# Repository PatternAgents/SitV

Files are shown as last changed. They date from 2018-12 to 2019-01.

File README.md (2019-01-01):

# Spoken into the Void - 




"Spoken into the Void" is an CPU upgrade/add-on for the Teensy3.2 CPU to the larger Teensy 3.5/3.6 CPU, 
yielding more memory space and other resouces. The upgrade is simple, remove the existing Teensy3.2 CPU, 
and plug in the "Spoken into the Void" board in it's place.

"Spoken into the Void" has the following features :

* Breadboard Friendly and Eurorack 3U/8HP compatible
* Teensy 3.6 Based (32 bit 120/240 MHz ARM Cortex-M4 processor with floating point unit and DSP)
* 4X Flash Upgrade (1.0 Megabyte)
* 4X RAM Upgrade   (256 Kilobytes)
* Supports up to two(2) Teensy Audio Shields for four(4) channel 16-bit Audio I/O
* 4X (optional/external)  Analog to digital converters (ADS1115 16-bit) for independent CV sampling
* USB Full-Speed Device (USB Audio, MIDI, COM, HID)
* USB Full-Speed Host (USB Keyboard, peripherals)
* Two  (2) AC coupled, line level audio input channels 
* Two  (2) AC coupled, line level audio output channels
* UART Jack for Serial MIDI Expansion
* I2C Jack for Controls & UI Expansion
* 32K bytes NVSRAM (non-volatile memory) for configuration memory (with Embedis support)

Format : Eurorack (3U/8HP)

Dimensions :  110mm x 40mm

Power : +5V (USB) 200mA

Jacks(Grove) : Stereo Line Input, Stereo Line Output, UART, I2C

---------------------------------------

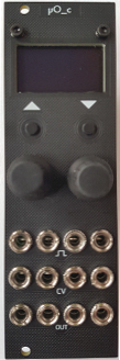
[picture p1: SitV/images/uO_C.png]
micro:O&C (https://github.com/patternagents/SitV)
  SitV (https://www.youtube.com/watch?v=XBFi51OQsEs)

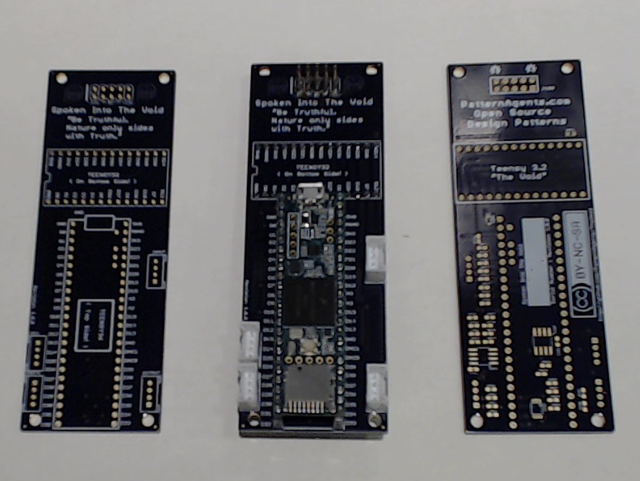
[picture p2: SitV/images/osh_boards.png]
SitV
[SitV](https://github.com/PatternAgents/SitV)

---------------------------------------
## SitV Applications <a name="SitV_Applications"/>

"Spoken into the Void" upgrades a [Teensy3.2 embedded CPU](https://www.pjrc.com/store/teensy32.html) Socket to accept the larger [Teensy 3.6 embedded CPU](https://www.pjrc.com/store/teensy36.html) module.
"Spoken into the Void" is designed to be compatible with the [Teensy Audio Shield](https://www.pjrc.com/store/teensy3_audio.html),
and can accept up to two shields, supporting up to four (4) 16 bit audio channels.

- "SitV" is also "breadboard friendly" and can be used to develop other circuits based on the Teensy 3.6 embedded CPU module
together with several Teensy Audio Modules.
- "SitV" can also be used with the [8HP micro:Ornament and Crime Eurorack module from JakPlug](https://github.com/jakplugg/uO_c)
- "SitV" can also be used with the [8HP micro:Temps Utile Eurorack module from JakPlug](https://github.com/jakplugg/T_u)

"SitV" is primarily a firmware development and testing tool, 
for developing new Eurorack based synthesizer modules and firmware.

----------------------------------------
## DSP Audio Pipeline

(Performance Test Pipeline - Subject to change in final versions!)
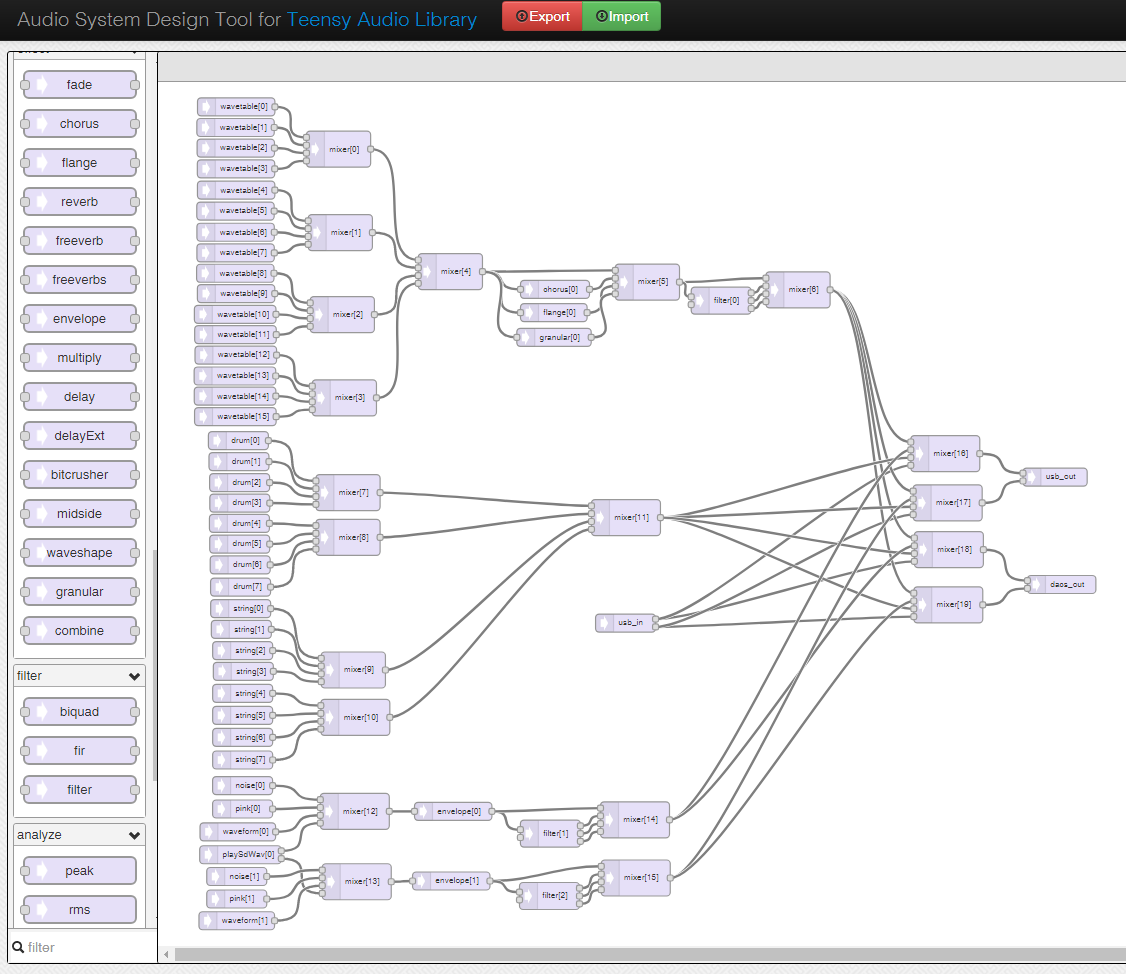
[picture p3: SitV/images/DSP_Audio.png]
SitV DSP Pipeline
[Spoken into the Void - DSP Pipeline](https://github.com/patternagents/SitV)

- 16 Wavetable Voices (with FX)
- 8 Drum Voices
- 8 String Voices
- 2 Noise/Complex Voices
- 2 SDcard .wav file Voices
- 2 USB Inputs
- 2 USB Outputs
- 2 Audio DAC (Line) Outputs

---------------------------------------
## SitV Status <a name="SitV_Status"/>

**11/28/2018:** 
- R1.0.0 : Initial Layout sent to OSHpark

**12/14/2018:**
- R1.0.0 : Initial Bringup and Testing
- Teensy3.5 working correctly
- Ornament&Crime R1.3.3 Up and Running on Teensy3.5
- Ornament&Crime R1.3.3 alternate SPI pins issue with O&C Core on Teensy3.6 (not running)

**12/23/2018:**
- "Serial+MIDIx16+Audio" compiles/runs with Hemishere 1.7A on Teensy 3.5 only
- "MIDIx16" to Serial4 MIDI router tests : Working on both 3.5 & 3.6

**01/01/2019:**
- rsvp_sitv: firmware update (raw testing version) Working on both 3.5 & 3.6
- rsvp_sitv: Serial+MIDIx16+Audio, OLED drivers Working on both 3.5 & 3.6

---------------------------------------
## SitV Model Images

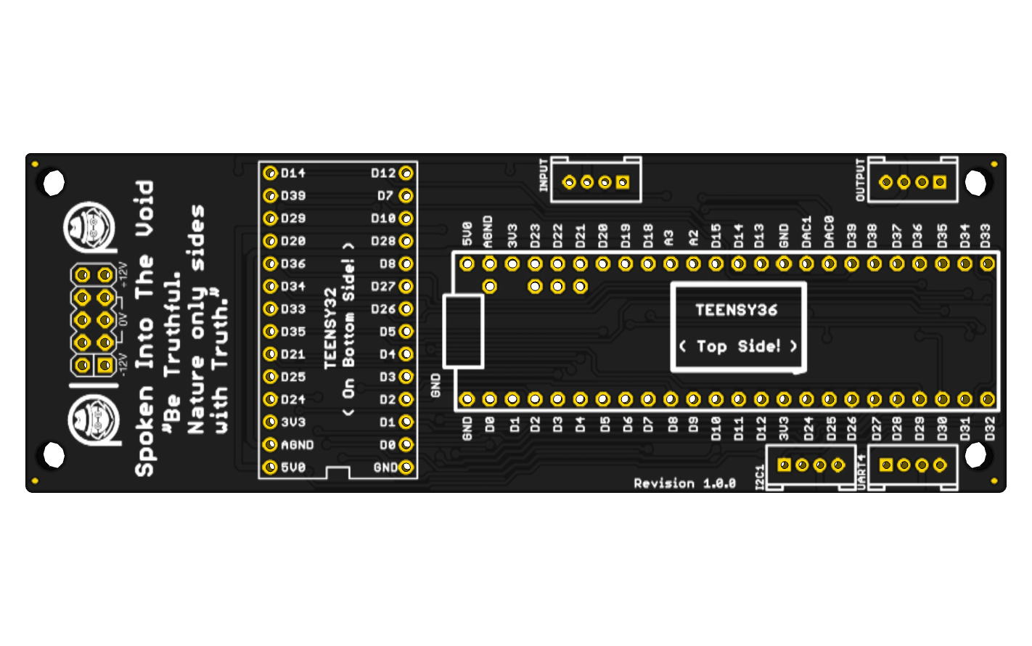
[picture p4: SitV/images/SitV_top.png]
[Spoken into the Void - Top Side](https://github.com/patternagents/SitV)

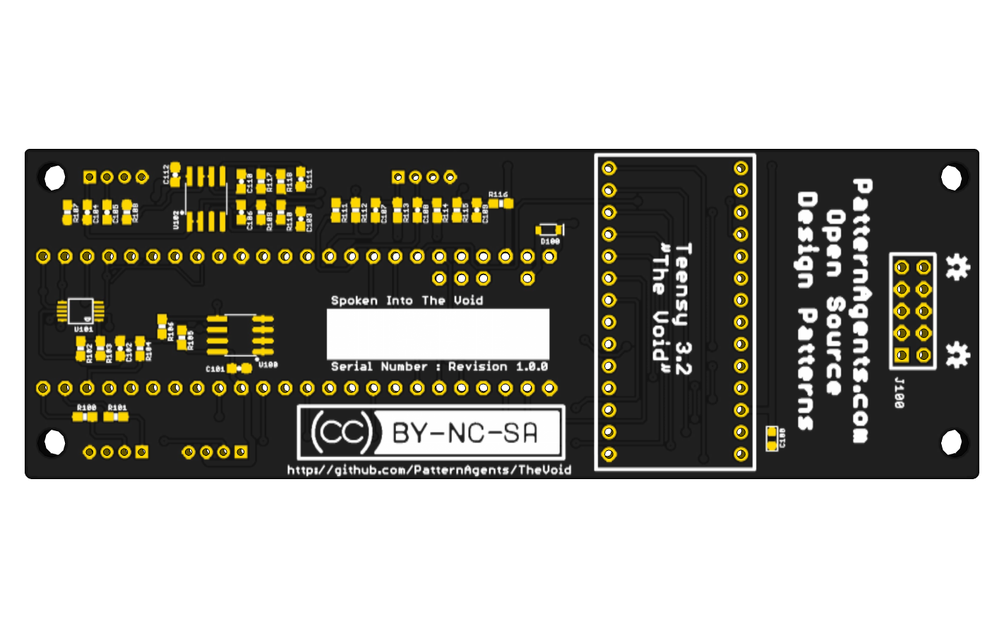
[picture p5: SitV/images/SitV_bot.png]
[Spoken into the Void - Bottom Side](https://github.com/patternagents/SitV)

---------------------------------------

## SitV Documentation Index <a name="TheVoid_documentation_index"/>

[Ornament and Crime](http://ornament-and-cri.me/)

[micro:Ornament and Crime](https://github.com/jakplugg/uO_c)

[SitV Project](https://github.com/PatternAgents/SitV/wiki)

[SitV Hardware](https://github.com/patternagents/SitV/tree/master/SitV/revisions/)

---------------------------------------

## Documentation Index <a name="documentation_index"/>

[Organization Website](http://patternagents.github.io)

[FAQ - Frequently Asked Questions](http://thingsoc.github.io/support/faq.html)

---------------------------------------

[thingSoC 
*PatternAgents, LLC*](http://thingsoc.github.io)

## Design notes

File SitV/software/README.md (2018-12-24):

# Spoken Into The Void - FIRMWARE

"Spoken Into The Void" can be used in several different applications.

When used with "Ornament and Crime" compatible hardware,
the following firmware can be used :

- o_c_V1_3_3_siv : Port of Ornment & Crime Version 1.3.3 for Teensy 3.5
- o_c_hemi_V1_7A_siv : Base Port of Hemisphere Suite Version 1.7A for Teensy 3.5
- rsvp-sitv : Base Port of Embedis/RSVP for Teensy 3.6
- tests : Assorted Hardware Testing routines for Teensy 3.5/3.6

---------------------------------------

## SitV Documentation Index <a name="SitV_documentation_index"/>

[Ornament and Crime](http://ornament-and-cri.me/)

[micro:Ornament and Crime](https://github.com/jakplugg/uO_c)

[SitV Project](https://github.com/PatternAgents/SitV/wiki)

[SitV Hardware](https://github.com/patternagents/SitV/tree/master/SitV/revisions/)

---------------------------------------

## Documentation Index <a name="documentation_index"/>

[Organization Website](http://patternagents.github.io)

[FAQ - Frequently Asked Questions](http://thingsoc.github.io/support/faq.html)

---------------------------------------

[thingSoC 
*PatternAgents, LLC*](http://thingsoc.github.io)

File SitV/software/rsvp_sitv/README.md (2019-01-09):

# Spoken Into The Void - RSVP

RSVP is a simple framework for using and testing embedded systems.

RSVP uses the Embedis console to interactively enter commands for testing.

See  "SDCARD/HELP.TXT" for help

--------------------------------------
## Contents

SDCARD    - copy contents to an SDcard for the Teensy3.6

libraries - install into Arduino/Libraries

rsvp_sitv - Arduino Source code

Requirements:

Teensy3.6 Module

Formatted SDcard

Arduino 1.8.8+

TeensyDuino 1.4.5+

Settings:

240Mhz (overclock)

Serial+MIDIx16+Audio

---------------------------------------

## SitV Documentation Index <a name="SitV_documentation_index"/>

[SitV Project](https://github.com/PatternAgents/SitV/wiki)

[SitV Hardware](https://github.com/patternagents/SitV/tree/master/SitV/revisions/)

---------------------------------------

## Documentation Index <a name="documentation_index"/>

[Organization Website](http://patternagents.github.io)

[FAQ - Frequently Asked Questions](http://thingsoc.github.io/support/faq.html)

---------------------------------------

[thingSoC 
*PatternAgents, LLC*](http://thingsoc.github.io)

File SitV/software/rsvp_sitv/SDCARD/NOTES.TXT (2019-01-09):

MIDI Routing
------------

0.0.1 : Simple 1:1 MIDI Routing, no filtering
	1) latency seems high?
        2) Might need to try reducing the Audio DSP overhead
	3) Polling loop issues/slow, recode as callbacks, etc.

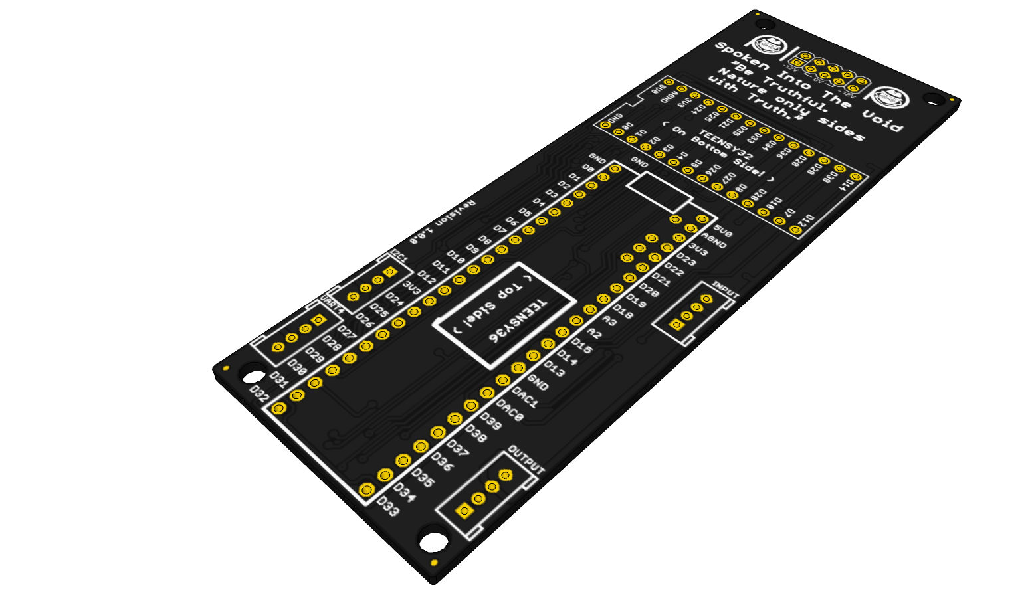
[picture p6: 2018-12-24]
SitV/images/SitV_iso.png

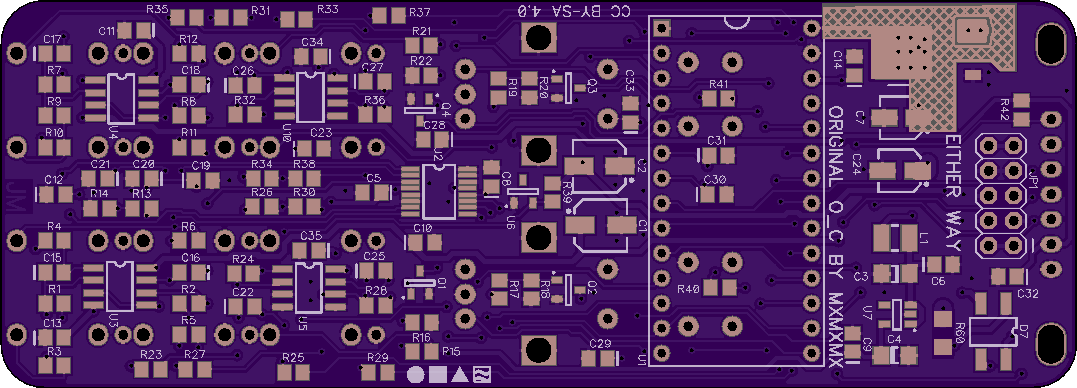
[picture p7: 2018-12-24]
SitV/images/uO_C_osh_bot.png

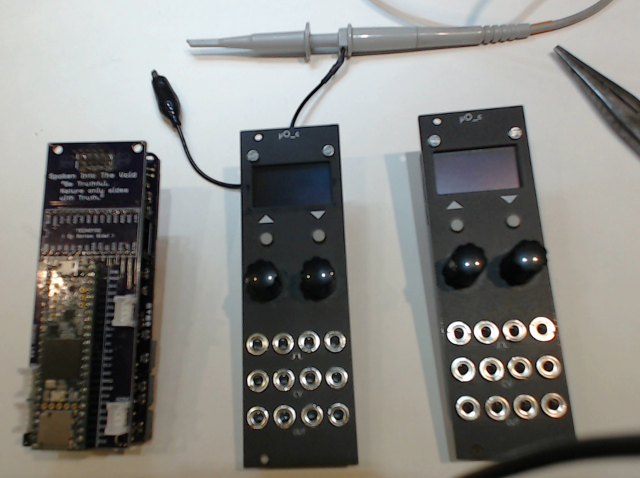
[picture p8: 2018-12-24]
SitV/images/osh_board5.png

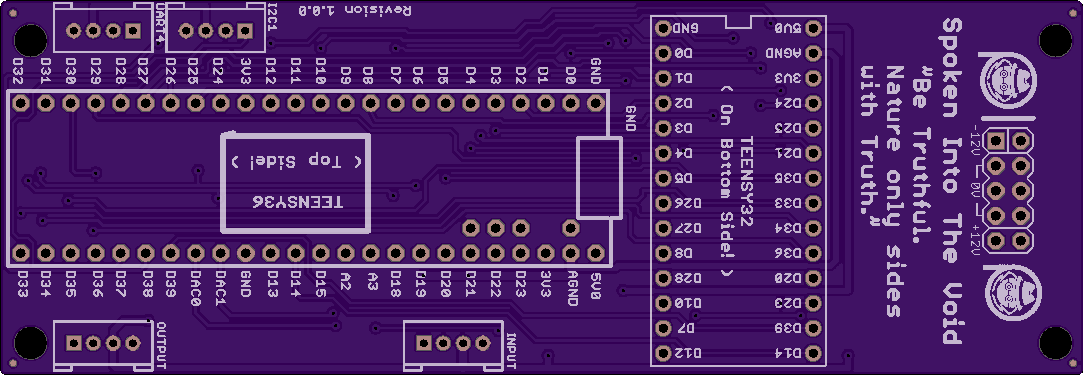
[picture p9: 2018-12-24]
SitV/images/osh_top.png

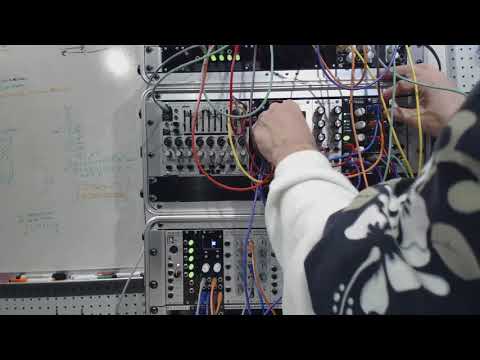
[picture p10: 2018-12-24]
SitV/images/in_rack.jpg

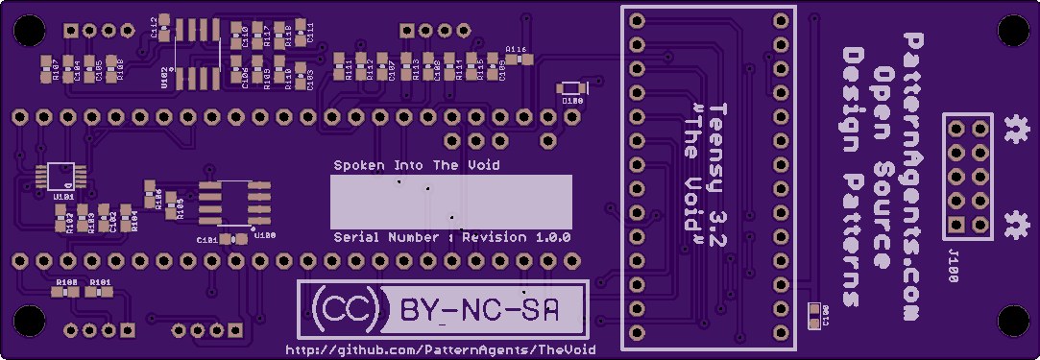
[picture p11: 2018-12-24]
SitV/images/osh_bot.png

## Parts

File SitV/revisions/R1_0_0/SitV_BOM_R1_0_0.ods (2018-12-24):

Qty | Parts | Value | Device | Price Each | Total Qty | Price Total | On Hand | Order | Source
2 | C106, C110 | 1000pF | CAP0603-CAP | 0.066 | 2 | 0.132 | 500 | 0 | https://www.mouser.com/ProductDetail/Yageo/CC0603MRX7R9BB102
4 | C100, C101, C102, C112 | 100nf | CERAMIC-100NF-50V-10%-X7R(0603) | 0.066 | 4 | 0.264 | 4000 | 0 | https://www.mouser.com/ProductDetail/Murata-Electronics/GCM033R71E471KA03D
2 | C103, C111 | 470pF | CAP0603-CAP | 0.066 | 2 | 0.132 | 500 | 0 | https://www.mouser.com/ProductDetail/Murata-Electronics/GCM033R71E471KA03D
5 | C104, C105, C107, C108, C109 | 10uF | CAP0603-CAP | 0.066 | 5 | 0.33 | 500 | 0 | https://www.mouser.com/ProductDetail/Taiyo-Yuden/JMK107BJ106MA-T
2 | R100, R101 | 1K | RESISTOR0603 | 0.02 | 2 | 0.04 | 4000 | 0 | https://www.mouser.com/ProductDetail/Yageo/RC0603FR-071KL?qs=sGAEpiMZZMtRY1MQzfviYBKl3q7m6O1t
3 | R105, R106, R115 | 2K2 | RESISTOR0603 | 0.02 | 3 | 0.06 | 4000 | 0 | https://www.mouser.com/ProductDetail/Yageo/RC0603FR-072K2L?qs=sGAEpiMZZMtRY1MQzfviYIolhRbATB6G
4 | R109, R110, R117, R118 | 7K5 | RESISTOR0603 | 0.02 | 4 | 0.08 | 0 | 100 | ttps://www.mouser.com/ProductDetail/KOA-Speer/RK73H1JTTD7501D
3 | R103, R104, R116 | 10K | RESISTOR0603 | 0.02 | 3 | 0.06 | 5000 | 0 | https://www.mouser.com/ProductDetail/Yageo/RC0603FR-0710KL?qs=sGAEpiMZZMvLNADcllXbqHQ2CGarwjoT
4 | R111, R112, R113, R114 | 47K | RESISTOR0603 | 0.02 | 4 | 0.08 | 5000 | 0 | https://www.mouser.com/ProductDetail/Yageo/RC0603FR-0747KL?qs=sGAEpiMZZMtRY1MQzfviYPBNqk%2fPjiRr
3 | R102, R107, R108 | DNP | RESISTOR0603 | 0 | 3 | 0 | 0 | 0 | https://www.mouser.com/ProductDetail/Yageo/RC0603FR-0747KL?qs=sGAEpiMZZMtRY1MQzfviYPBNqk%2fPjiRr
1 | D100 | 0.5A/40V/420mV | DIODE-SCHOTTKY-SOD323 | 0.3 | 1 | 0.3 | 15 | 0 | https://www.mouser.com/ProductDetail/Nexperia/PMEG4005EJ115?qs=sGAEpiMZZMvKM5ialpXrmgQgxdAV4sRu
1 | U100 | FM24W256-G | FM24W256-G-SO08 | 6.7 | 1 | 6.7 | 5 | 0 | https://www.mouser.com/ProductDetail/Cypress-Semiconductor/FM24W256-G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
1 | U101 | ADS1115IDGST | ADC_ADS1015-MSOP10 | 5.36 | 1 | 5.36 | 0 | 5 | https://www.mouser.com/ProductDetail/Texas-Instruments/ADS1115IDGSR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
1 | U102 | MCP6002-SO08 | MCP6002-SO08 | 0.35 | 1 | 0.35 | 28 | 0 | https://www.mouser.com/ProductDetail/Microchip-Technology/MCP6002T-I-SN?qs=sGAEpiMZZMsUzhEcHltCuY6YBL510a4u
2 | T32L, T32R | 1x14-2.54MM-MALE-PIN | TEENSY_3.0-3.2&LC_DIL | 0.25 | 2 | 0.5 | 0 | 5 | https://www.ebay.com/itm/1x40-Pin-40P-2-54mm-Straight-Male-Header-Body-Centered-17mm-Black-Pack-of-5/381315745725
2 | T36L, T36R | 1X24-2.54MM-FEMALE | TEENSY_3.5/3.6_BASIC | 0.25 | 2 | 0.5 | 0 | 5 | https://www.ebay.com/itm/20pc-Female-Pin-Header-Pitch-2-54mm-H-8-5mm-Straight-type-1x24p-1x24-24p-RoHS/140891861219
1 | J100 | 2X05-2.54MM-FEMALE | 2X05_EUROPWR_LONG | 0.5 | 1 | 0.5 | 0 | 5 | https://www.ebay.com/itm/20pcs-2-54mm-2x5-10pin-Long-Legs-Double-Row-Female-stackable-Straight-Header/271558168930
4 | I2C1, INPUT, OUTPUT, UART4 | 4P-2.0 | GROVE-CONNECTOR-DIP(4P-2.0) | 0.1 | 4 | 0.4 | 50 | 5 | https://www.robotshop.com/en/seeedstudio-grove-4-pin-connector.html
1 | PCB | PCB | PCB | 10 | 1 | 10 | 3 | 0 | https://github.com/PatternAgents/TheVoid
1 | T3.6 | TEENSY3.6 | TEENSY3.6 | 33.25 | 1 | 33.25 | 0 | 1 | https://www.pjrc.com/store/teensy36_pins.html
1 | LABOR | ASSEMBLY | ASSEMBLY | 60 | 1 | 60 | 0 | 0 | https://github.com/PatternAgents/TheVoid
 | TOTAL COST |  |  |  |  | 119.038
 | RESALE |  |  | 150 | 1 | 150
 | PROFIT |  |  |  |  | 30.962

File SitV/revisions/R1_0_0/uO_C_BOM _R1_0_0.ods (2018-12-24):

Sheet: BOM
Quantity | Value | Name | RefDes | Mouser | Notes | Price Each | Total Qty | Price Total | On Hand | Order
 |  |  |  | Capacitors
4 | 22pf | CAP_0805 | C15, C16, C17, C18 | 77-VJ0805A220GXAPBC (https://www.mouser.com/Search/ProductDetail.aspx) | or 18p | 0.113 | 12 | 1.356 |  | 100 | https://www.mouser.com/ProductDetail/Wurth-Electronics/885012007030
4 | 560pf | CAP_0805 | C22, C25, C26, C27 | 77-VJ0805A561JXAAC (http://www.mouser.com/ProductDetail/Vishay-Vitramon/VJ0805A561JXAAC/?qs=ReTA%2F0kwlVYgsqJl6lJxLg%3D%3D) |  | 0.077 | 12 | 0.924 |  | 100 | https://www.mouser.com/ProductDetail/KEMET/C0805C561M8HACTU
16 | 0.1uf | CAP_0805 | C5, C6, C8, C9, C10, C11, C12, C13, C19, C20, C21, C30, C31, C32, C34, C35 | 80-C0805C104K5R (https://www.mouser.com/Search/ProductDetail.aspx) |  | 0.077 | 48 | 3.696 | 12 | 200 | https://www.mouser.com/ProductDetail/KEMET/C0805C104M5RACTU
3 | 0.47uf | CAP_0805 | C14, C29, C33 | 581-080516C474K (https://www.mouser.com/ProductDetail/AVX/0805YC474KAT2A/) |  | 0.1 | 9 | 0.9 |  | 100 | https://www.mouser.com/ProductDetail/KEMET/C0805C104M5RACTU
2 | 1uf | CAP_0805 | C23, C28 | 81-GCM21BR71H105KA3L (https://www.mouser.com/Search/ProductDetail.aspx) |  | 0.25 | 6 | 1.5 |  | 50 | https://www.mouser.com/ProductDetail/Wurth-Electronics/885012207078
2 | 10uf | CAP_1206 | C3, C4 | 81-GRM319R61E106KA2D (https://www.mouser.com/ProductDetail/Murata-Electronics/GRM319R61E106KA12D/) |  | 0.4 | 6 | 2.4 | 49 | 0
2 | 22uf | CPOL-USC | C1, C2 | 667-EEE-FK1V220R (https://www.mouser.com/Search/ProductDetail.aspx) | 35V | 0.25 | 6 | 1.5 | 16 | 35
2 | 10uf | CPOL-USC | C7, C24 | 667-EEE-FK1E100R (https://www.mouser.com/Search/ProductDetail.aspx) | 25V | 0.2 | 6 | 1.2 |  | 35
 |  |  |  | Resistors
1 | 4.7 | R-US_R1206 | R60 | 660-RK73B2BTTDD4R7J (http://www.mouser.com/ProductDetail/KOA-Speer/RK73B2BTTDD4R7J/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) |  | 0.11 | 3 | 0.33 |  | 50
4 | 100 | RES_0805 | R25, R29, R33, R37 | 660-RK73H2ATTD1000F (http://www.mouser.com/ProductDetail/KOA-Speer/RK73H2ATTD1000F/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) |  | 0.11 | 12 | 1.32 |  | 100
4 | 220 | RES_0805 | R4, R6, R10, R12 | 279-CPF0805B220RE1 (https://www.mouser.com/Search/ProductDetail.aspx) | 0.10% | 0.25 | 12 | 3 |  | 50 | https://www.mouser.com/ProductDetail/TE-Connectivity-Neohm/CPF0805B220RE1
2 | 510 | RES_0805 | R40, R41 | 603-RC0805JR-07510RL (https://www.mouser.com/Search/ProductDetail.aspx) |  | 0.11 | 6 | 0.66 |  | 100
1 | 2k | RES_0805 | R39 | 660-RK73H2ATTE2001F (https://www.mouser.com/Search/ProductDetail.aspx) |  | 0.11 | 3 | 0.33 |  | 100
1 | 10k | RES_0805 | R42 | 660-RK73H2ATTD1002F (https://www.mouser.com/Search/ProductDetail.aspx) |  | 0.11 | 3 | 0.33 | 35 | 100
4 | 24k9 | RES_0805 | R1, R2, R7, R8 | 756-PCF0805R-24K9BT1 (https://www.mouser.com/Search/ProductDetail.aspx) | 0.10% | 0.25 | 12 | 3 |  | 50
8 | 33k | RES_0805 | R16, R18, R20, R22, R24, R28, R32, R36 | 660-RK73H2ATTD3302F (https://www.mouser.com/Search/ProductDetail.aspx) |  | 0.11 | 24 | 2.64 |  | 100
2 | 47k | RES_0805 | R13, R14 | 660-RK73H2ATTD4702F (https://www.mouser.com/Search/ProductDetail.aspx) |  | 0.11 | 6 | 0.66 |  | 100
4 | 75k | RES_0805 | R26, R30, R34, R38 | 660-RK73H2ATTD7502F (https://www.mouser.com/Search/ProductDetail.aspx) |  | 0.11 | 12 | 1.32
12 | 100k | RES_0805 | R3, R5, R9, R11, R15, R17, R19, R21, R23, R27, R31, R35 | 279-CPF0805B100KE (https://www.mouser.com/Search/ProductDetail.aspx) | 0.10% | 0.25 | 36 | 9 |  | 50+100
 |  |  |  | Inductor
1 | 10uH |  | L1 | 963-LB3218T100K (https://www.mouser.com/Search/ProductDetail.aspx) |  | 0.12 | 3 | 0.36 | 7 | 10
 |  |  |  | Semiconductors
1 |  | DAC8565 | U2 | 595-DAC8565ICPW (https://www.mouser.com/Search/ProductDetail.aspx) |  | 15 | 3 | 45 | 1 | 3
1 |  | LM4040_EM3-5.0 | U6 | 926-LM4040DIM350NOPB (https://www.mouser.com/Search/ProductDetail.aspx) |  | 0.65 | 3 | 1.95 | 0 | 10
1 | ADP150 3.3V | ADP150 3.3V | U7 | 584-ADP150AUJZ-3.3R7 (https://www.mouser.com/Search/ProductDetail.aspx) |  | 1 | 3 | 3 | 2 | 5
1 | MB1S | MB1S | D7 | 512-MB1S (https://www.mouser.com/Search/ProductDetail.aspx?R=MB1Svirtualkey51210000virtualkey512-MB1S) |  | 0.3 | 3 | 0.9 | 8 | 10
2 |  | MCP6002 | U5, U10 | 579-MCP6002T-I/SN (https://www.mouser.com/Search/ProductDetail.aspx) |  | 0.35 | 6 | 2.1 | 28 | 0
4 |  | MMBT3904 | Q1, Q2, Q3, Q4 | 512-MMBT3904 (https://www.mouser.com/Search/ProductDetail.aspx?R=MMBT3904virtualkey51210000virtualkey512-MMBT3904) |  | 0.12 | 12 | 1.44 | 99 | 0
2 |  | OPA2172 | U3, U4 | 595-OPA2172IDR (https://www.mouser.com/Search/ProductDetail.aspx) |  | 1.65 | 6 | 9.9 | 6 | 5
1 | LM1117-5 | REG1117T | IC6 | 511-LD1117DT50C-TR (https://www.mouser.com/Search/ProductDetail.aspx) |  | 0.4 | 3 | 1.2 | 10
 |  |  |  | Controls
1 |  | OLED | OLED |  | 7 pin,128x64 | 10 | 3 | 30 | 3 | 0
2 |  | PEC11 | E1, E2 | 858-EN11-HSM1BF20 (http://www.mouser.com/ProductDetail/TT-Electronics/EN11-HSM1BF20/) |  | 1.1 | 6 | 6.6 |  | 10
2 |  | 6mm Tactile SW | U8, U9 | 612-TL1105SPF100Q (https://www.mouser.com/Search/ProductDetail.aspx) |  | 0.3 | 6 | 1.8 | 11 | 0
2 |  | Tact Caps |  | 612-1R-RD (https://www.mouser.com/Search/ProductDetail.aspx?R=1RREDvirtualkey61200000virtualkey612-1R-RD) | BLK, WHT | 0.17 | 6 | 1.02 | 11 | 0
12 |  | Thonkiconn | J1, J2, J3, J4, J5, J6, J7, J8, J9, J10, J11, J12 |  | Thonk | 0.4 | 36 | 14.4 | 100 | 0
1 | 10 pin power header | M05X2PTH | JP1 | 49-67996-410HLF (https://www.mouser.com/Search/ProductDetail.aspx) |  | 1 | 3 | 3 | 12 | 0
 |  |  |  | Other Hardware
1 |  | Teensy3.2 | Teensy3.2 |  | Teensy3.2 | 20 | 3 | 60 |  | 2
1 |  | PCB | PC Board |  | PC Board | 10 | 3 | 30 |  | 0
1 |  | Front Panel | Front Panel |  | Front Panel | 10 | 3 | 30
2 |  | Davies Knobs | Knobs |  | Knobs | 1.75 | 6 | 10.5
2 |  | Nuts |  | 481-0007 (http://www.mouser.com/ProductDetail/Eagle-Plastic-Devices/481-0007/?qs=sGAEpiMZZMv9NFGNGF1lwip6rtQWoF3E) | M7 Nuts | 0.36 | 6 | 2.16
2 |  | Spacers |  | 761-M0505-25-N (http://www.mouser.com/ProductDetail/RAF-Electronic-Hardware/M0505-25-N/) | M2.5 Spacers | 0.8 | 6 | 4.8
4 |  | Bolts |  | 534-29301 (http://www.mouser.com/ProductDetail/Keystone-Electronics/29301/) | M2.5,10mm | 0.35 | 12 | 4.2
6 |  | Washers |  |  | Nylon M2.5 | 0.35 | 18 | 6.3
1 |  | Labor |  |  |  | 100 | 3 | 300
Total Costs |  |  |  |  |  |  |  | 606.696
Resale |  |  |  |  |  | 280 | 3 | 840
Royalties |  |  |  |  |  | 20 | 3 | 60
Profit |  |  |  |  |  |  |  | 173.304

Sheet: DISPLAY PCB
Quantity | Value | Name | RefDes | Mouser | Other | Notes
1 |  | 1306_disp_O_C | U11 |  | http://www.buydisplay.com/default/serial-spi-1-3-inch-128x64-oled-display-module-ssd1306-white-on-black
4 | 10K | RESISTOR0603MINI | R2, R4, R5, R6 |  | Resistors
1 | 390K | RESISTOR0603MINI | R3 |  | Resistors
5 | 2.2uF | CAP_CERAMIC0603MINI | C3, C4, C6, C7, C8 |  | Ceramic Capacitors
1 | 10uF | CAP_CERAMIC0603MINI | C5 |  | Ceramic Capacitors
1 |  | HEADER-1X7ROUND | JP1 |  | PIN HEADER
1 |  | DISPLAY PCB |  |  | https://oshpark.com/shared_projects/3olQy5tV

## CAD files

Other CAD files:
SitV/models/SitV.skp

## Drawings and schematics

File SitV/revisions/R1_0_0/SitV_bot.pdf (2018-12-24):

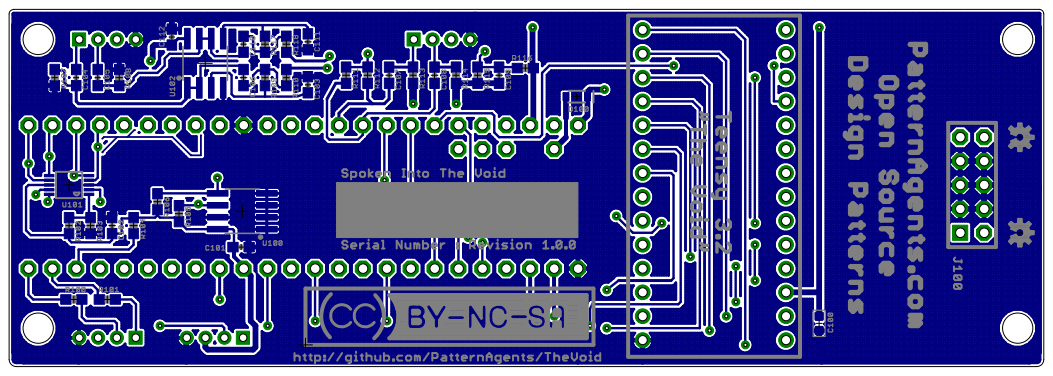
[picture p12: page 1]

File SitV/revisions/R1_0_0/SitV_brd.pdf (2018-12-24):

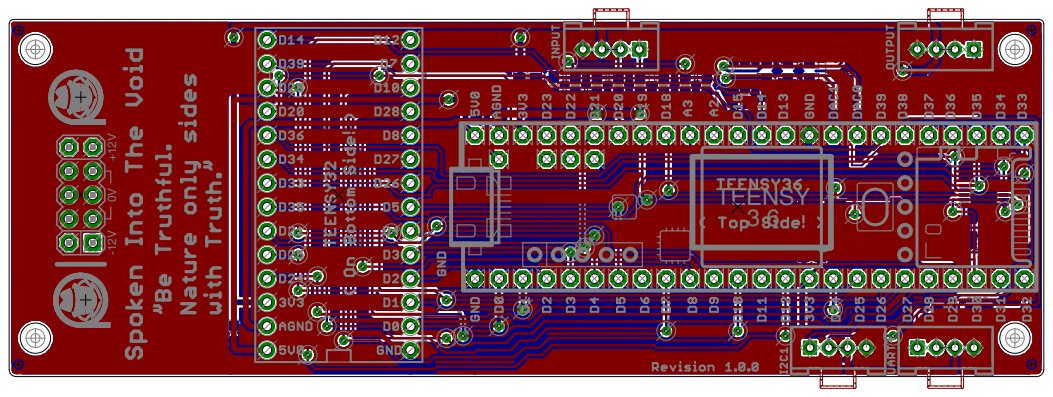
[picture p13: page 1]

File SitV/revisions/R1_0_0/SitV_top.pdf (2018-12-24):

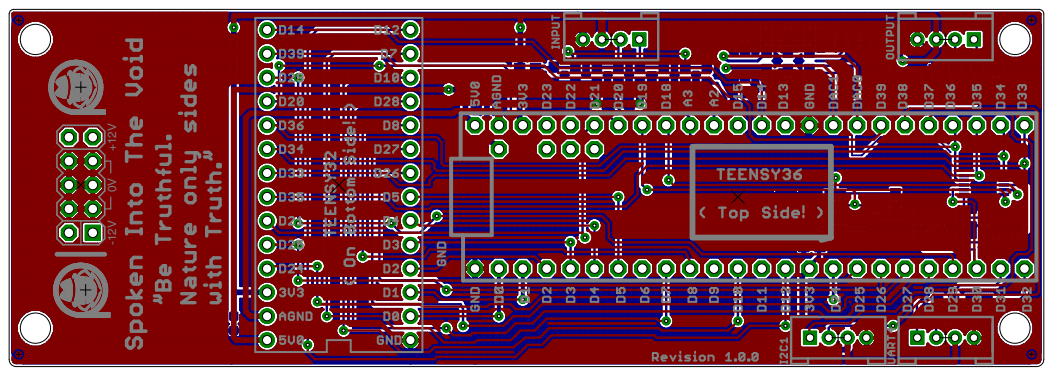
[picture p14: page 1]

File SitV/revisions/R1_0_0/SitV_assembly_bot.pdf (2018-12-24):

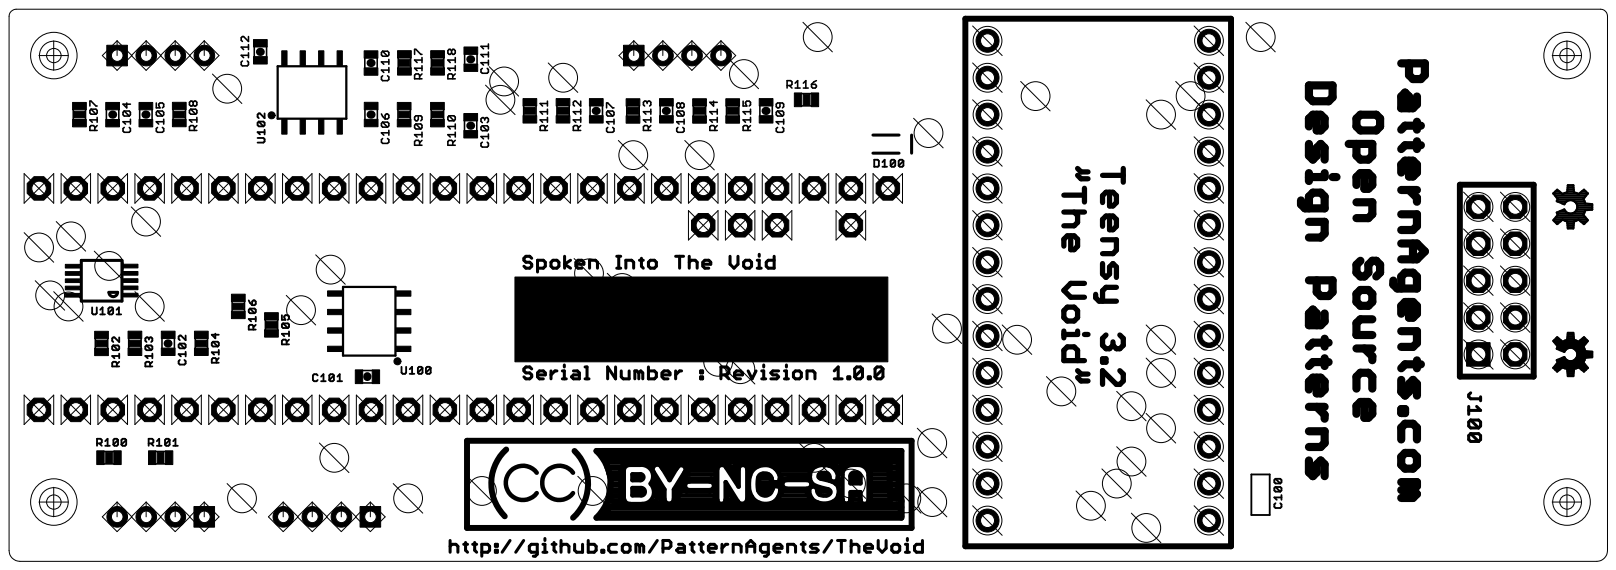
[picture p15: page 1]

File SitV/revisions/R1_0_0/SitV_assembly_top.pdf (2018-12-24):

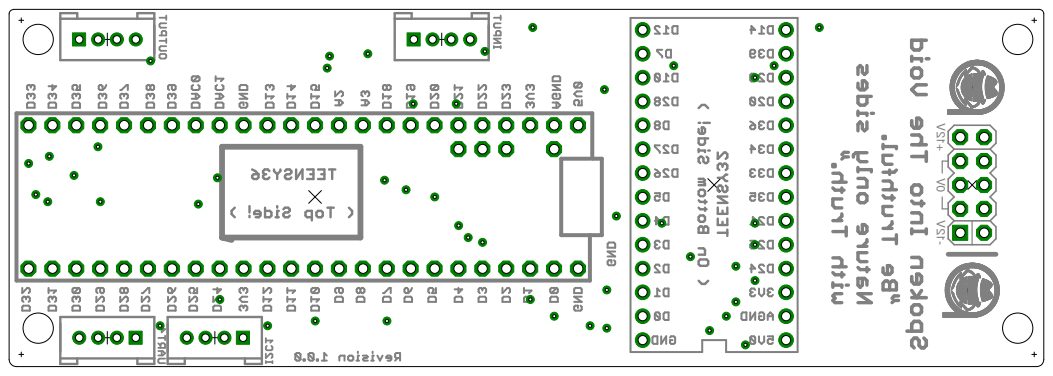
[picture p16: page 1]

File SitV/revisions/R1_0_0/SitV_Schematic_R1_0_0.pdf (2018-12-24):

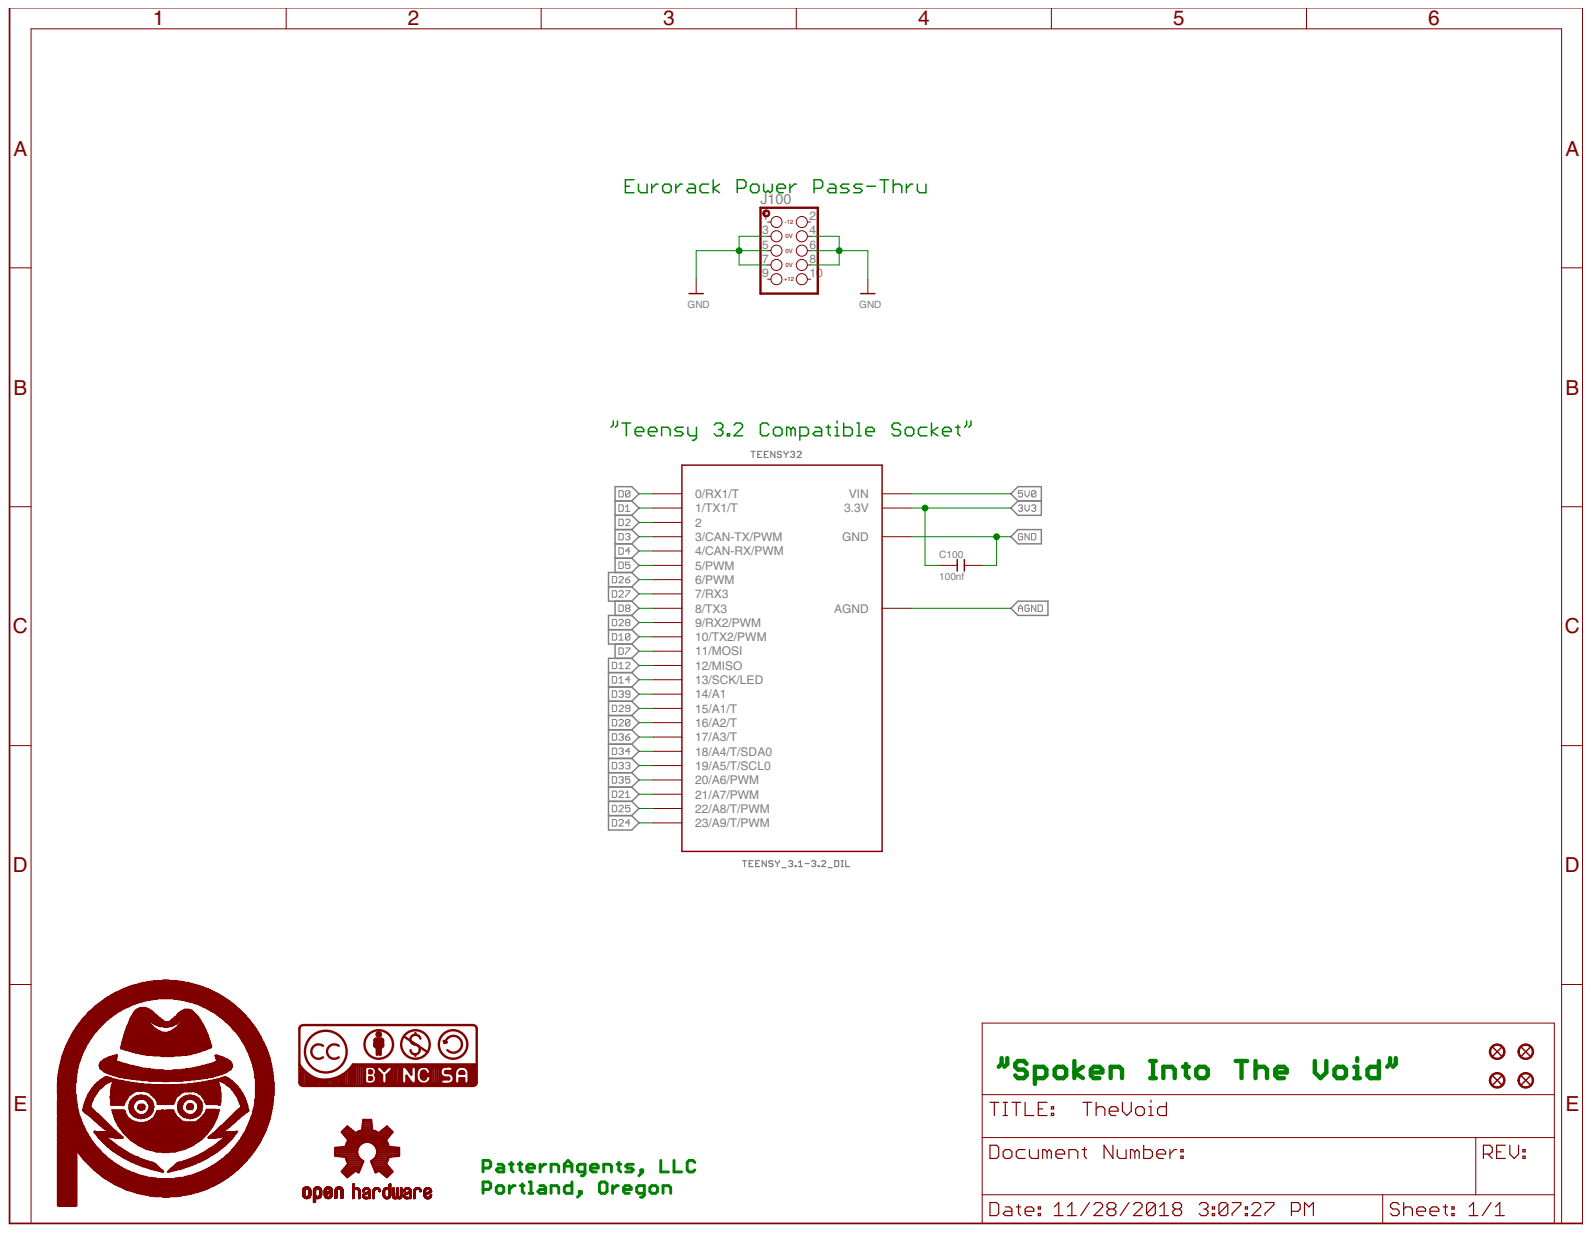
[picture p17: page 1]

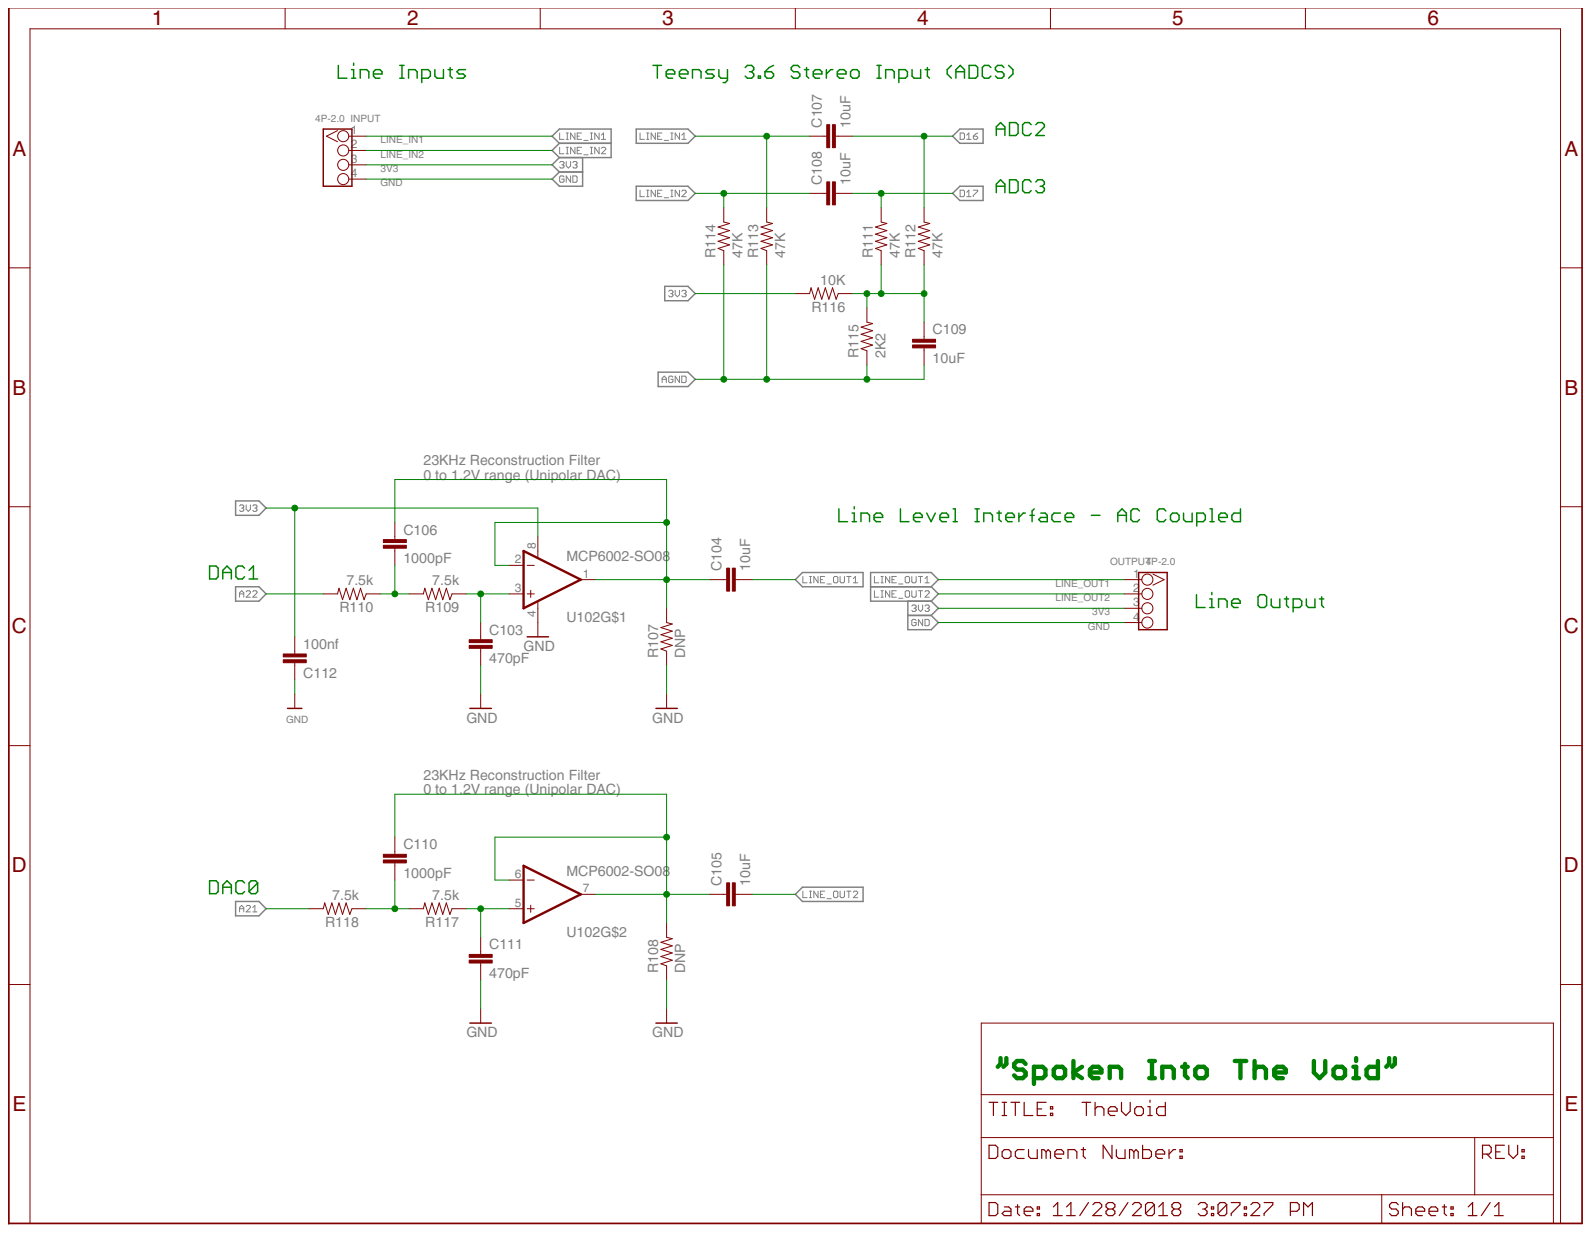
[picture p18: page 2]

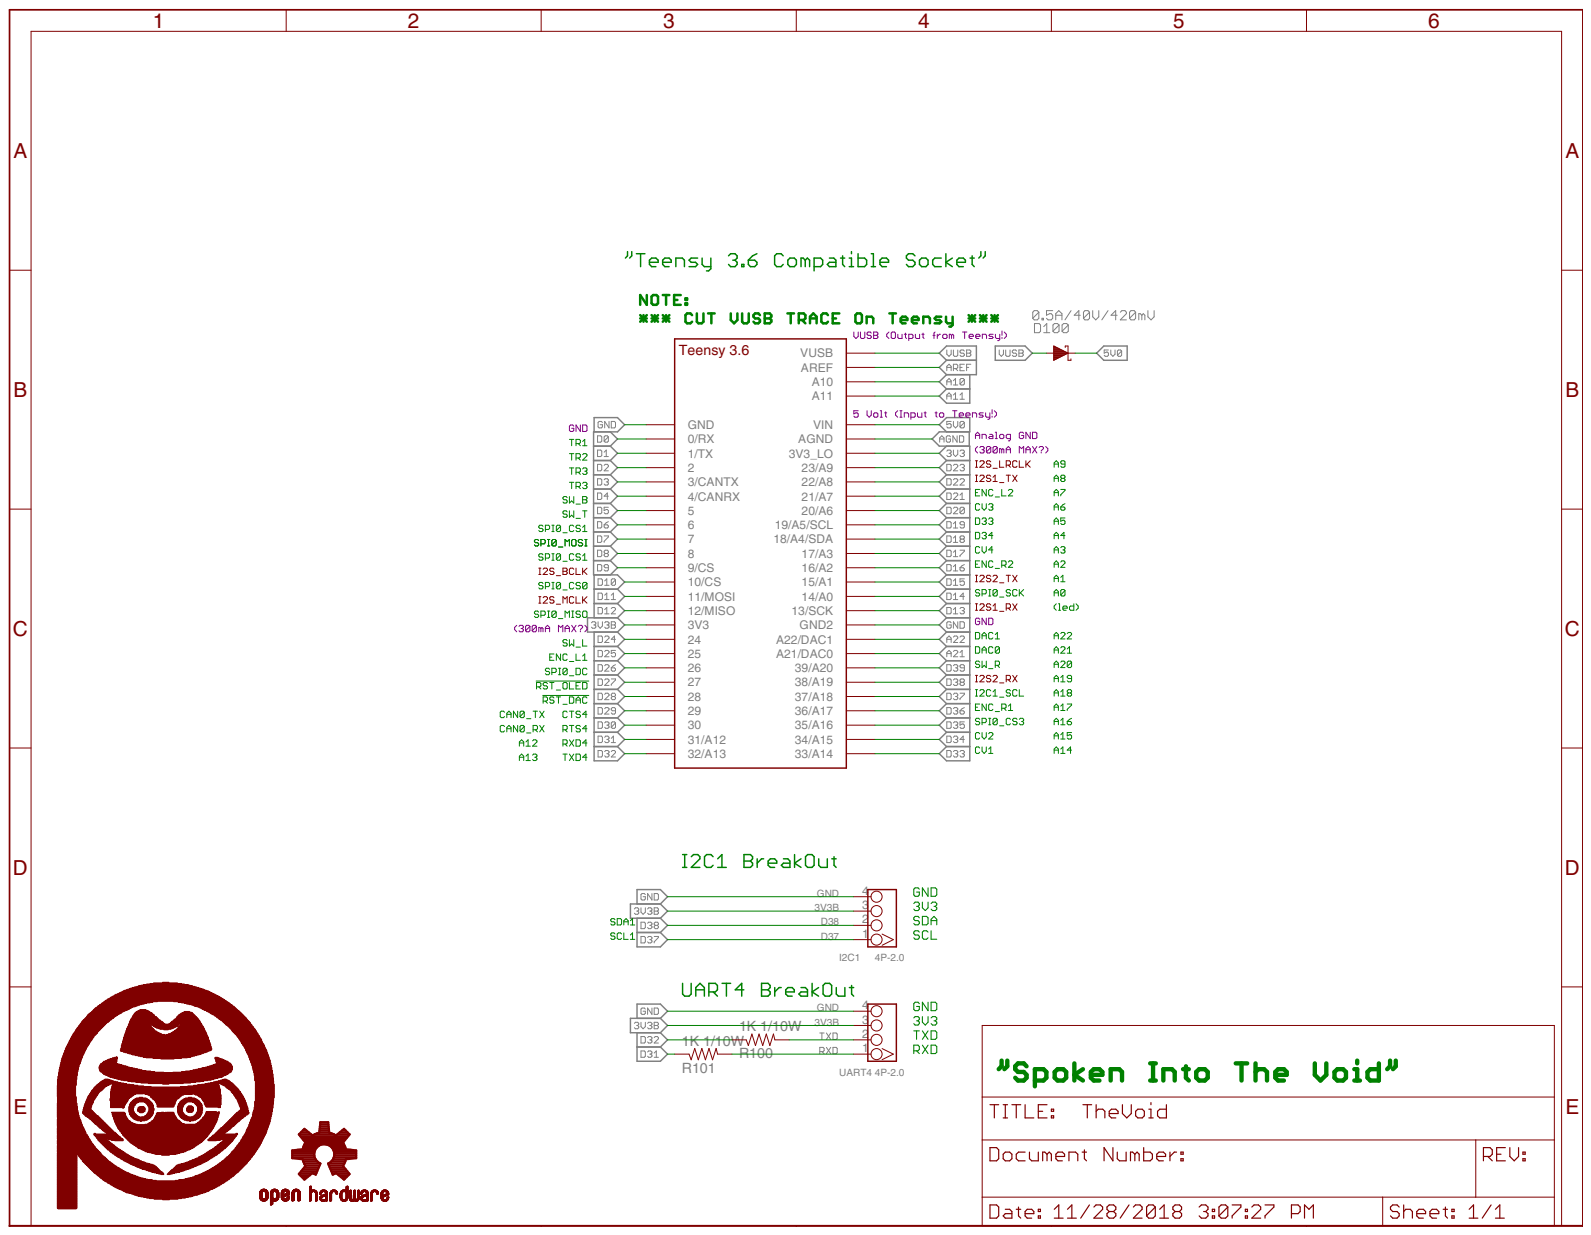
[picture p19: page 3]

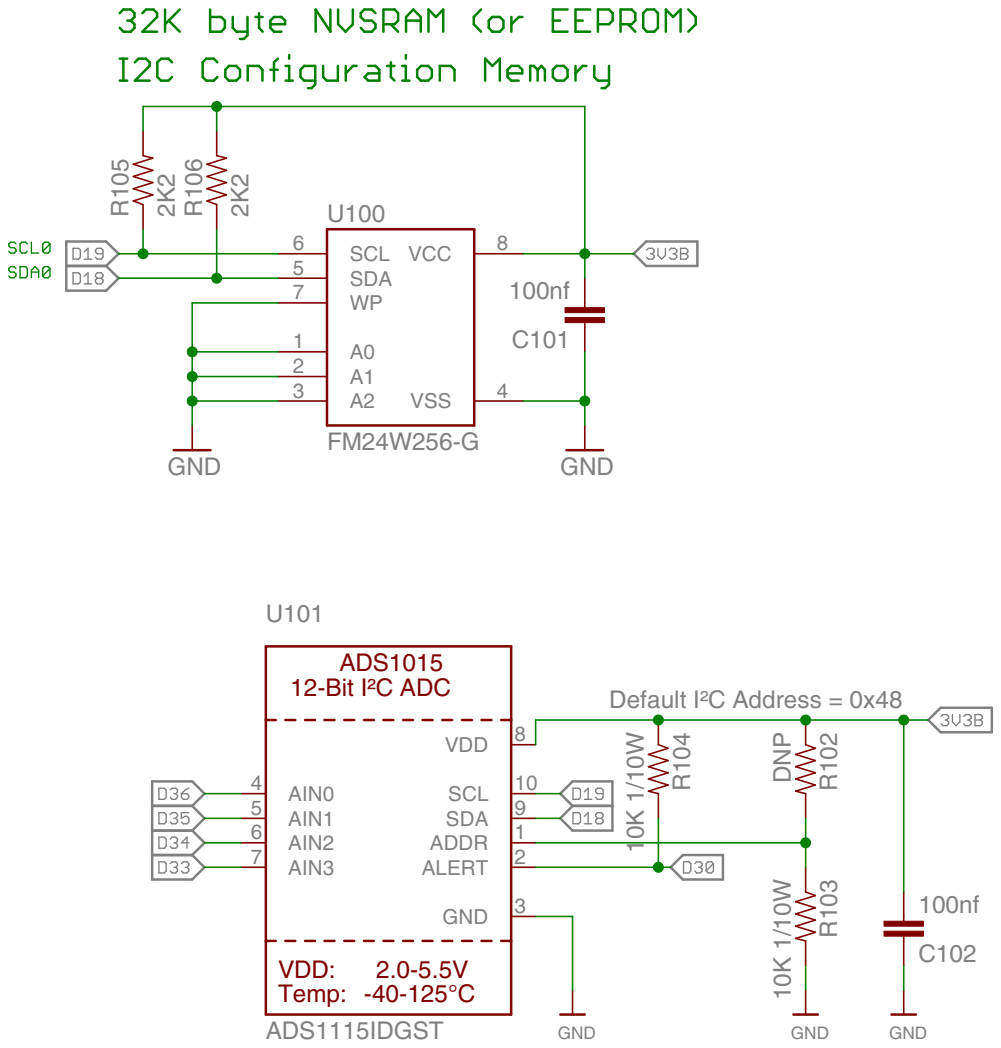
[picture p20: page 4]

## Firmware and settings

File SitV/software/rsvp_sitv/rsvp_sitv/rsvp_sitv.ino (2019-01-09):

/*  rsvp - Reference System Virtual Platform
    Copyright (C) 2015, 2016, 2017, 2018 PatternAgents, LLC

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
    You should have received a copy of the GNU General Public License
    along with this program.  If not, see <http://www.gnu.org/licenses/>.
*/
/*
   ====================================================================================== 

    "Spoken Into The Void" & QuadroTeenia Hardware Platforms
    --------------------------------------------------------

    Intended for 3.5, 3.6, 4.0 portability over raw performance
    (we'll see how well that goes...)

    Current SitV Teensy 3.6 Test Settings
    -------------------------------------
    Board: Teensy 3.6
    USB Type: Serial + MIDIx16 + Audio
    CPU Speed: 240Mhz (Overclock)
    
   ======================================================================================
*/

/* apps will fill in the upper tabs, the rsvp framework is under ./src */
#include "src/rsvp/rsvp.h"

/* basic templates to start - add apps once the core is tested */
void setup() {
  /* rsvp - initialize all subsystems */
  rsvp_setup();
}

void loop() {
    /* run-  the rsvp stacks */
    rsvp_loop();
}

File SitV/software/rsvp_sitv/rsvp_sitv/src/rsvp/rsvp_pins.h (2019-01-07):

/*  rsvp_pins.h - platform pins definition */

#ifndef RSVP_PINS_H_
#define RSVP_PINS_H_

#include "rsvp_options.h"

#if (RSVP_PLATFORM == SITV)
  // "Spoken Into The Void" and "QuadtroTeenia" Pin Outs for Teensy 3.5 & 3.6"
  #if (RSVP_DISPLAY_ORIENTATION == 0)
    #define CV4 33  //19
    #define CV3 34  //18
    #define CV2 35  //20
    #define CV1 36  //17

    #define TR4 0
    #define TR3 1
    #define TR2 2
    #define TR1 3
  
    #define but_top 4
    #define but_bot 5
  #else
    #define CV1 33  //19
    #define CV2 34  //18
    #define CV3 35  //20
    #define CV4 36  //17
  
    #define TR1 0
    #define TR2 1
    #define TR3 2
    #define TR4 3
  
    #define but_top 5
    #define but_bot 4
  #endif

// NOTE: encoder pins R1/R2 changed for rev >= 2c
  #if (RSVP_DISPLAY_ORIENTATION == 0)
    #define encL1 20  //16
    #define encL2 29  //15
    #define butL  39  //14
  
    #define encR1 25  //22
    #define encR2 21  //21
    #define butR  24  //23
  #else
    #define encR1 20  //16
    #define encR2 29  //15
    #define butR  39  //14
  
    #define encL1 25  //22
    #define encL2 21  //21
    #define butL  24  //23
  #endif

  // SPI Bus
  #define OLED_DC   26        //6-26**
  #define OLED_RST  27        //7-27
  #define OLED_CS    8        //8-10
  #define OLED_MOSI  7        //11-7**
  #define OLED_MISO 12        //12-12
  #define OLED_SCK  14


  #define DAC_RST   28        //9
  #define DAC_CS    10        //10-8
  #define DAC_MOSI   7        //11
  #define DAC_MISO   12       //12
  #define DAC_SCK   14        //13

 // DEBUG PINS NOTE: back side :(
      #define OC_GPIO_DEBUG              2  //number of DEBUG pins
      #define OC_GPIO_DEBUG_PIN1        54  // was 24
      #define OC_GPIO_DEBUG_PIN2        55  // was 25

 // Pin Modes
      #define OC_GPIO_BUTTON_PINMODE    INPUT_PULLUP
      #define OC_GPIO_TRx_PINMODE       INPUT_PULLUP
      #define OC_GPIO_ENC_PINMODE       INPUT_PULLUP
      
 // OLED CS is active low
      #define OLED_CS_ACTIVE            LOW
      #define OLED_CS_INACTIVE          HIGH
     
  // MIDI Bus    
      #define RSVP_MIDI_PINS    2   // number of MIDI pins 
                                    // 0=Not Enabled 1=In Only, 2 = In + Out, 3= In + Out + Clk, 4 = All
      #define RSVP_MIDI_PORT   Serial4                        
      #define RSVP_MIDI_IN     31   // MIDI RXD
      #define RSVP_MIDI_OUT    32   // MIDI TXD
      #define RSVP_MIDI_CLK    49   // Note : Backside pins
      #define RSVP_MIDI_RUN    50   // Note : Backside pins

  // GATE OUT Bus
      #define RSVP_GTO_PINS     0    // number of QT GATE_OUT (GTO) pins
                                   // 0=Not Enabled
      #define RSVP_GTO1        43
      #define RSVP_GTO2        44
      #define RSVP_GTO3        45
      #define RSVP_GTO4        46

// DAC OUT BUS
      #define RSVP_IDAC_PINS     2    // number of (internal) DAC pins
                                      // 0=Not Enabled
      #define RSVP_IDAC_RESOL   12    // number of DAC bits
      #define RSVP_IDAC1       A21
      #define RSVP_IDAC2       A22

// I2S OUT BUS
      #define RSVP_I2S_PINS      0        // number of I2S pins/channels
                                        // 0-3=Not Enabled, 4=TXD12, 5=+RXD12, 6=+TXD34, 7=Quad In/Out)
      #define RSVP_I2S_TYPE      SGTL5000 // I2S type
      #define RSVP_I2S_I2C_PORT  0        // I2C Control Bus number
      #define RSVP_I2S_I2C_ADRM  0x0A     // I2C Control Bus address (master)
      #define RSVP_I2S_I2C_ADRS  0x1A     // I2C Control Bus address (slave)
      #define RSVP_I2S_BCLK      9
      #define RSVP_I2S_MCLK     11
      #define RSVP_I2S_LRCLK    23
      #define RSVP_I2S_TXD12    22
      #define RSVP_I2S_RXD12    13
      #define RSVP_I2S_TXD34    22
      #define RSVP_I2S_RXD34    13

 // ADC IN
      #define RSVP_ADC_PINS      0        // number of ADC pins/channels
                                        // 0=Not Enabled
      #define RSVP_ADC_TYPE      ADS1015  // ADC type
      #define RSVP_ADC_I2C_PORT  0        // ADC Control Bus number
      #define RSVP_ADC_I2C_ADRM  0x48     // ADC Control Bus address (master=0)
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

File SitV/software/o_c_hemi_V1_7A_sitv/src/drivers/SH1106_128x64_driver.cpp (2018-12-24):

/*
*   (C) Copyright 2011, Oli Kraus
*   (C) Copyright 2013, Andrew Kroll (xxxajk)
*   (C) Copyright 2016, Patrick Dowling
*
*   Low-level driver code for SH1106 OLED with spicy DMA transfer.
*   Author: Patrick Dowling (pld@gurkenkiste.com)
*
*   Command sequences adapted from https://github.com/olikraus/u8glib/blob/master/csrc/u8g_dev_ssd1306_128x64.c
*   SPI transfer command adapted from https://github.com/xxxajk/spi4teensy3
*
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
*   This program is distributed in the hope that it will be useful,
*   but WITHOUT ANY WARRANTY; without even the implied warranty of
*   MERCHANTABILITY or FITNESS FOR A PARTICULAR PURPOSE.  See the
*   GNU General Public License for more details.
*/


#include <Arduino.h>
#include "SH1106_128x64_driver.h"
#include "../../OC_gpio.h"
#include "../../OC_options.h"

//#define DMA_PAGE_TRANSFER TWM
#ifdef DMA_PAGE_TRANSFER
#include <DMAChannel.h>
static DMAChannel page_dma;
#endif
#ifndef SPI_SR_RXCTR
#define SPI_SR_RXCTR 0XF0
#endif

static uint8_t SH1106_data_start_seq[] = {
// u8g_dev_ssd1306_128x64_data_start
  0x10, /* set upper 4 bit of the col adr to 0 */
  0x02, /* set lower 4 bit of the col adr to 0 */
  0x00  /* 0xb0 | page */  
};

static uint8_t SH1106_init_seq[] = {
// u8g_dev_ssd1306_128x64_adafruit3_init_seq
  0x0ae,          /* display off, sleep mode */
  0x0d5, 0x080,   /* clock divide ratio (0x00=1) and oscillator frequency (0x8) */
  0x0a8, 0x03f,   /* multiplex ratio, duty = 1/32 */

  0x0d3, 0x000,   /* set display offset */
  0x040,          /* start line */

  0x08d, 0x014,   /* [2] charge pump setting (p62): 0x014 enable, 0x010 disable */

  0x020, 0x000,   /* 2012-05-27: page addressing mode */ // PLD: Seems to work in conjuction with lower 4 bits of column data?
  #ifdef FLIP_180
  0x0a0,          /* segment remap a0/a1*/
  0x0c0,          /* c0: scan dir normal, c8: reverse */
  #else
  0x0a1,          /* segment remap a0/a1*/
  0x0c8,          /* c0: scan dir normal, c8: reverse */
  #endif
  0x0da, 0x012,   /* com pin HW config, sequential com pin config (bit 4), disable left/right remap (bit 5) */
  0x081, 0x0cf,   /* [2] set contrast control */
  0x0d9, 0x0f1,   /* [2] pre-charge period 0x022/f1*/
  0x0db, 0x040,   /* vcomh deselect level */
  
  0x02e,        /* 2012-05-27: Deactivate scroll */ 
  0x0a4,        /* output ram to display */
#ifdef INVERT_DISPLAY
  0x0a7,        /* inverted display mode */
#else
  0x0a6,        /* none inverted normal display mode */
#endif
  //0x0af,      /* display on */
};

static uint8_t SH1106_display_on_seq[] = {
  0xaf
};

/*static*/
void SH1106_128x64_Driver::Init() {
  pinMode(OLED_CS, OUTPUT);
  pinMode(OLED_RST, OUTPUT);
  pinMode(OLED_DC, OUTPUT);
  //SPI_init(); 

  // u8g_teensy::U8G_COM_MSG_INIT
  digitalWriteFast(OLED_RST, HIGH);
  delay(1);
  digitalWriteFast(OLED_RST, LOW);
  delay(10);
  digitalWriteFast(OLED_RST, HIGH);

  // u8g_dev_ssd1306_128x64_adafruit3_init_seq
  digitalWriteFast(OLED_CS, OLED_CS_INACTIVE); // U8G_ESC_CS(0),             /* disable chip */
  digitalWriteFast(OLED_DC, LOW); // U8G_ESC_ADR(0),           /* instruction mode */

  digitalWriteFast(OLED_RST, LOW); // U8G_ESC_RST(1),           /* do reset low pulse with (1*16)+2 milliseconds */
  delay(20);
  digitalWriteFast(OLED_RST, HIGH);
  delay(20);

  digitalWriteFast(OLED_CS, OLED_CS_ACTIVE); // U8G_ESC_CS(1),             /* enable chip */

  SPI_send(SH1106_init_seq, sizeof(SH1106_init_seq));

  digitalWriteFast(OLED_CS, OLED_CS_INACTIVE); // U8G_ESC_CS(0),             /* disable chip */

#ifdef DMA_PAGE_TRANSFER
  page_dma.destination((volatile uint8_t&)SPI0_PUSHR);
  page_dma.transferSize(1);
  page_dma.transferCount(kPageSize);
  page_dma.disableOnCompletion();
  page_dma.triggerAtHardwareEvent(DMAMUX_SOURCE_SPI0_TX);
  page_dma.disable();
#endif

  Clear();
}

/*static*/
void SH1106_128x64_Driver::Flush() {
#ifdef DMA_PAGE_TRANSFER
  // Assume DMA transfer has completed, else we're doomed
  digitalWriteFast(OLED_CS, OLED_CS_INACTIVE); // U8G_ESC_CS(0)
  page_dma.clearComplete();
  page_dma.disable();
  // DmaSpi.h::post_finishCurrentTransfer_impl
  SPI0_RSER = 0;
  SPI0_SR = 0xFF0F0000;
#endif
}

static uint8_t empty_page[SH1106_128x64_Driver::kPageSize];

/*static*/
void SH1106_128x64_Driver::Clear() {
  memset(empty_page, 0, sizeof(kPageSize));

  SH1106_data_start_seq[2] = 0xb0 | 0;
  digitalWriteFast(OLED_DC, LOW);
  digitalWriteFast(OLED_CS, OLED_CS_ACTIVE);
  SPI_send(SH1106_data_start_seq, sizeof(SH1106_data_start_seq));
  digitalWriteFast(OLED_DC, HIGH);
  for (size_t p = 0; p < kNumPages; ++p)
    SPI_send(empty_page, kPageSize);
  digitalWriteFast(OLED_CS, OLED_CS_INACTIVE); // U8G_ESC_CS(0)

  digitalWriteFast(OLED_DC, LOW);
  digitalWriteFast(OLED_CS, OLED_CS_ACTIVE);
  SPI_send(SH1106_display_on_seq, sizeof(SH1106_display_on_seq));
  digitalWriteFast(OLED_DC, HIGH);
}

/*static*/
void SH1106_128x64_Driver::SendPage(uint_fast8_t index, const uint8_t *data) {
  SH1106_data_start_seq[2] = 0xb0 | index;

  digitalWriteFast(OLED_DC, LOW); // U8G_ESC_ADR(0),           /* instruction mode */
  digitalWriteFast(OLED_CS, OLED_CS_ACTIVE); // U8G_ESC_CS(1),             /* enable chip */
  SPI_send(SH1106_data_start_seq, sizeof(SH1106_data_start_seq)); // u8g_WriteEscSeqP(u8g, dev, u8g_dev_ssd1306_128x64_data_start);
  digitalWriteFast(OLED_DC, HIGH); // /* data mode */

#ifdef DMA_PAGE_TRANSFER
  // DmaSpi.h::pre_cs_impl()
  SPI0_SR = 0xFF0F0000;
  SPI0_RSER = SPI_RSER_RFDF_RE | SPI_RSER_RFDF_DIRS | SPI_RSER_TFFF_RE | SPI_RSER_TFFF_DIRS;

  page_dma.sourceBuffer(data, kPageSize);
  page_dma.enable(); // go
#else
  SPI_send(data, kPageSize);
  digitalWriteFast(OLED_CS, OLED_CS_INACTIVE); // U8G_ESC_CS(0)
#endif
}
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

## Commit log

2018-12-24 initial version
    [TheVoid.skp, TheVoid_BOM_R1_0_0.ods, Xen-harmonic.xlsx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]
2018-12-24 add assembly drawings
2018-12-29 add SPI/OLED tests
2019-01-07 add DSP commands, filter, mixer, wave

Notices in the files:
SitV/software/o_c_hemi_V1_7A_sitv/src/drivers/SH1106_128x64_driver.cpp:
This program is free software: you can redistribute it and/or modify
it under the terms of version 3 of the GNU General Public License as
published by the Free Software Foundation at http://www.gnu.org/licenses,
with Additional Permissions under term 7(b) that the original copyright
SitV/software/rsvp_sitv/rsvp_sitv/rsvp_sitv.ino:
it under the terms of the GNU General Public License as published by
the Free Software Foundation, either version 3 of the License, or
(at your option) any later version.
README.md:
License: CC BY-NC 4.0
